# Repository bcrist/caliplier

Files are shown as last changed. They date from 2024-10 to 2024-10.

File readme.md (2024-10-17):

# Digital Caliper USB interface & LED Display

This project interfaces with the serial data output port found on cheap digital calipers.  It does several things:

* Provides power to the calipers
* Provides a second readout which isn't physically constrained by the measurement location/orientation
* Emulates a USB HID keyboard and "types" the current measurement at the press of a button
* Emulates a USB CDC-ACM serial port for logging/debug

There are many different variations on the serial format output by different calipers.  Some use 24-bit integers, some use BCD.  Some always output in inches, some always in mm, and some in whatever format the internal display is currently using.  Some include error detection data, others don't.  Currently there is only one protocol supported:

* Data signal is stable whenever Clock signal is high
* 24-bit packet, transferred over 8.1ms (+/- 0.1ms)
* First bit is always 1
* Next 20 bits are the unsigned magnitude (little-endian)
* Next bit is 1 if negative
* Last two bits are unused
* There is no indication whether it is in mm or inches mode.  In mm mode, 1 ULP is 0.01mm, and in inches mode, 1 ULP is 0.0005".
* The bus is idle for at least 5ms between packets



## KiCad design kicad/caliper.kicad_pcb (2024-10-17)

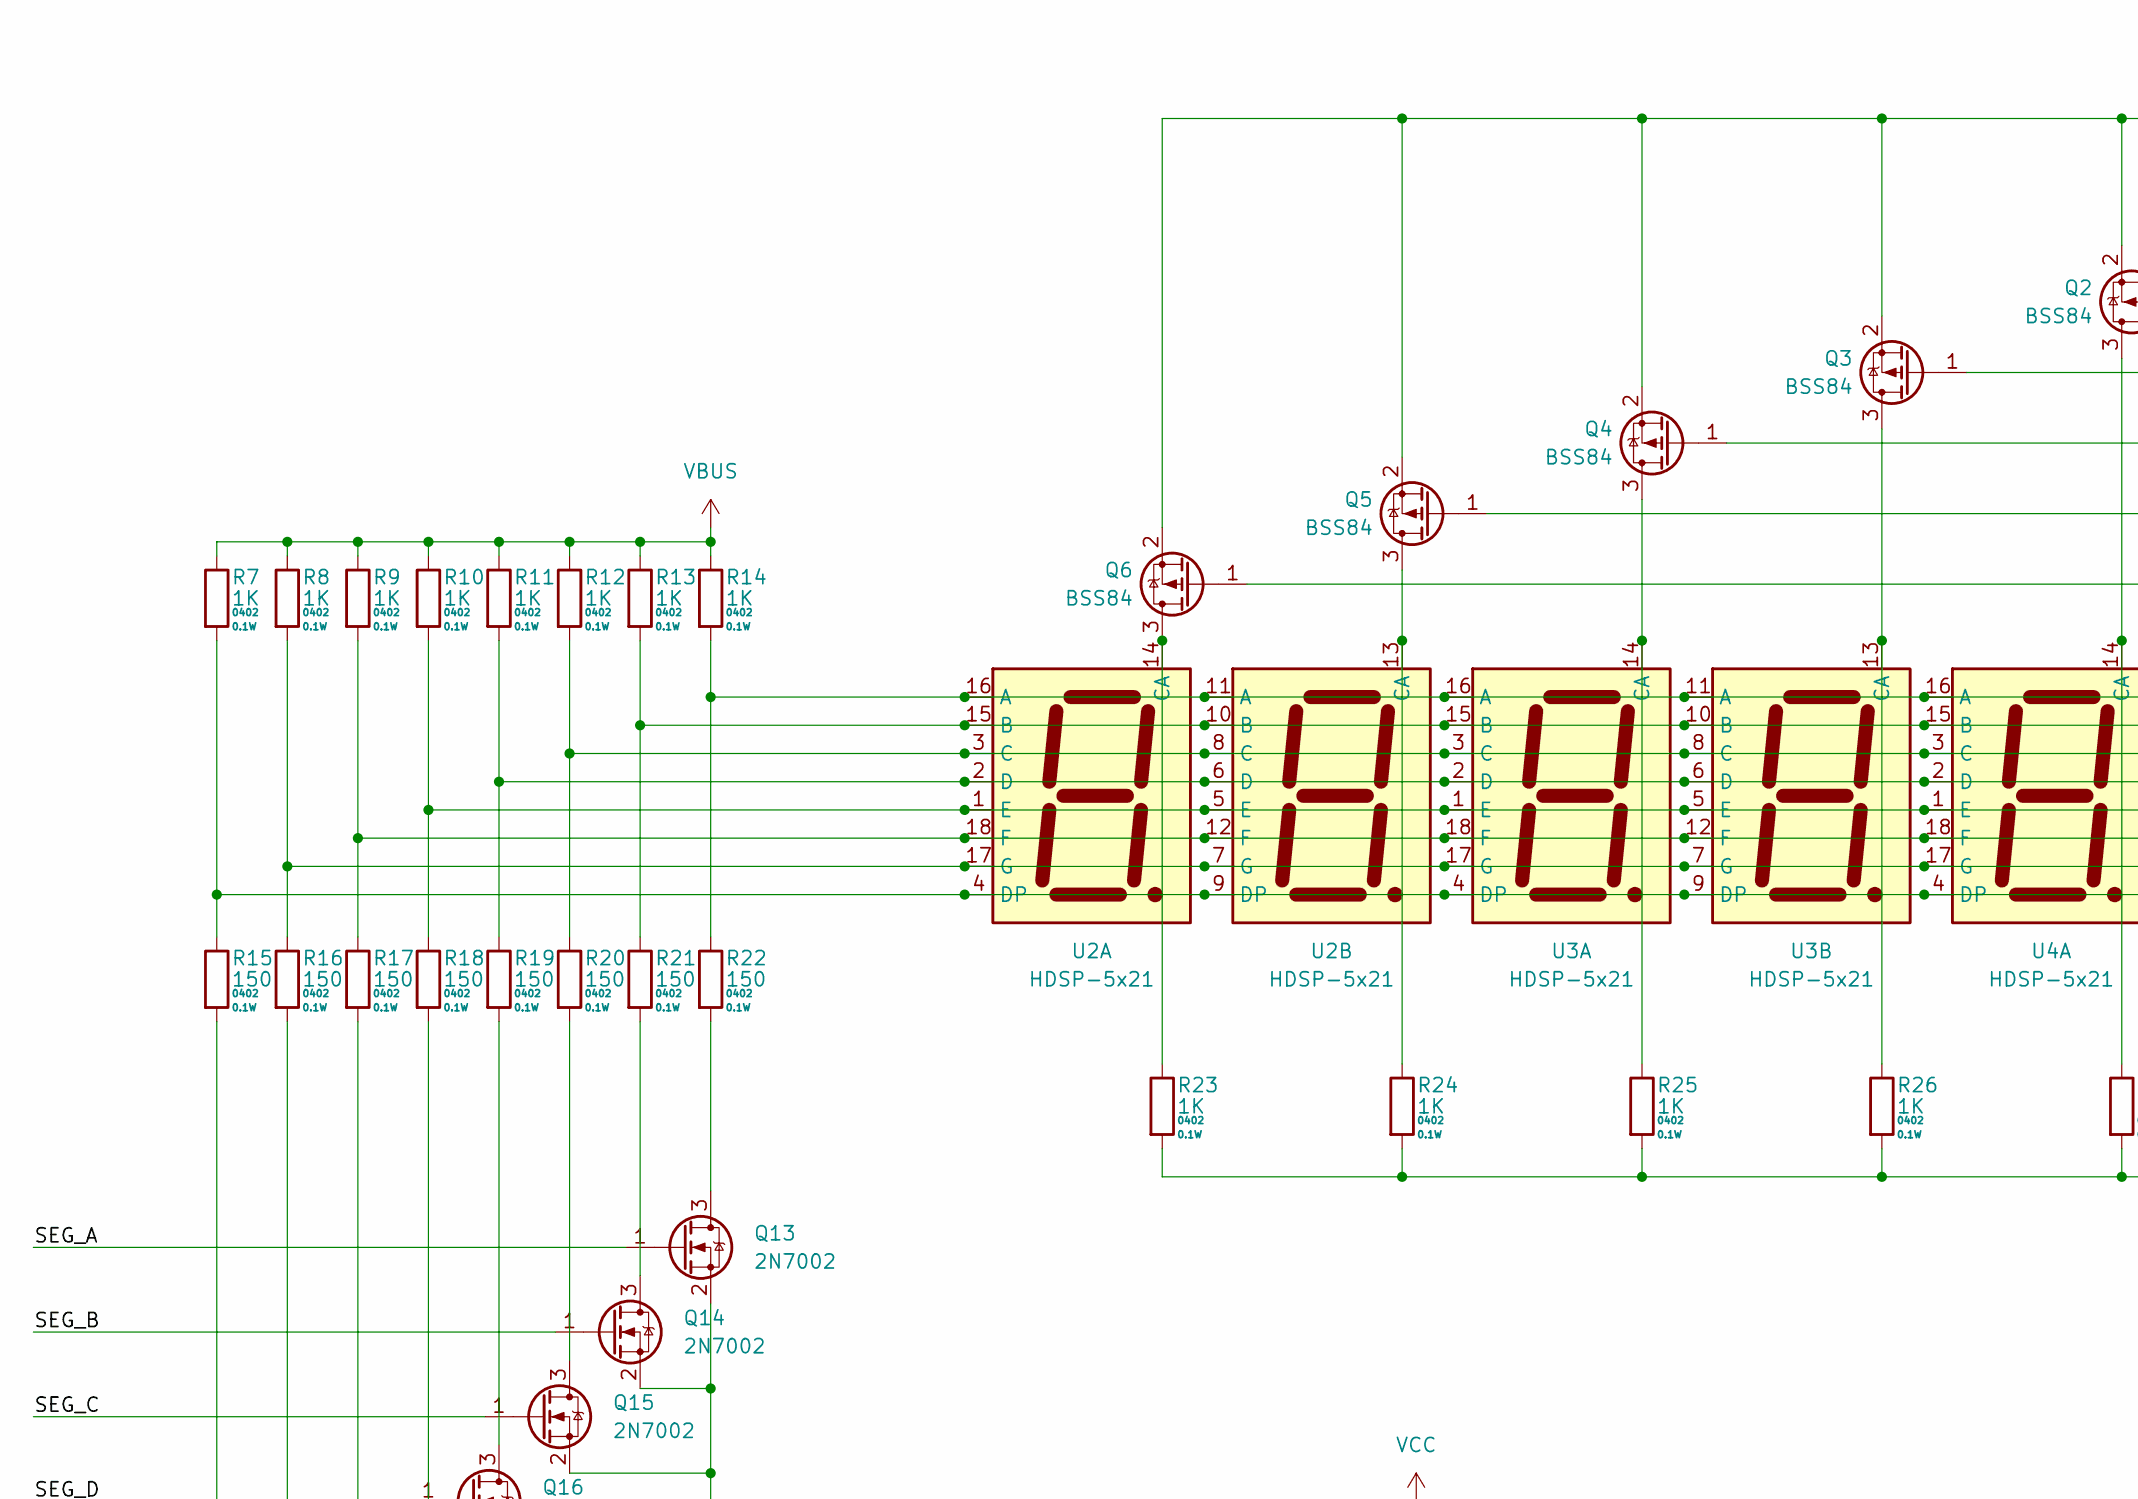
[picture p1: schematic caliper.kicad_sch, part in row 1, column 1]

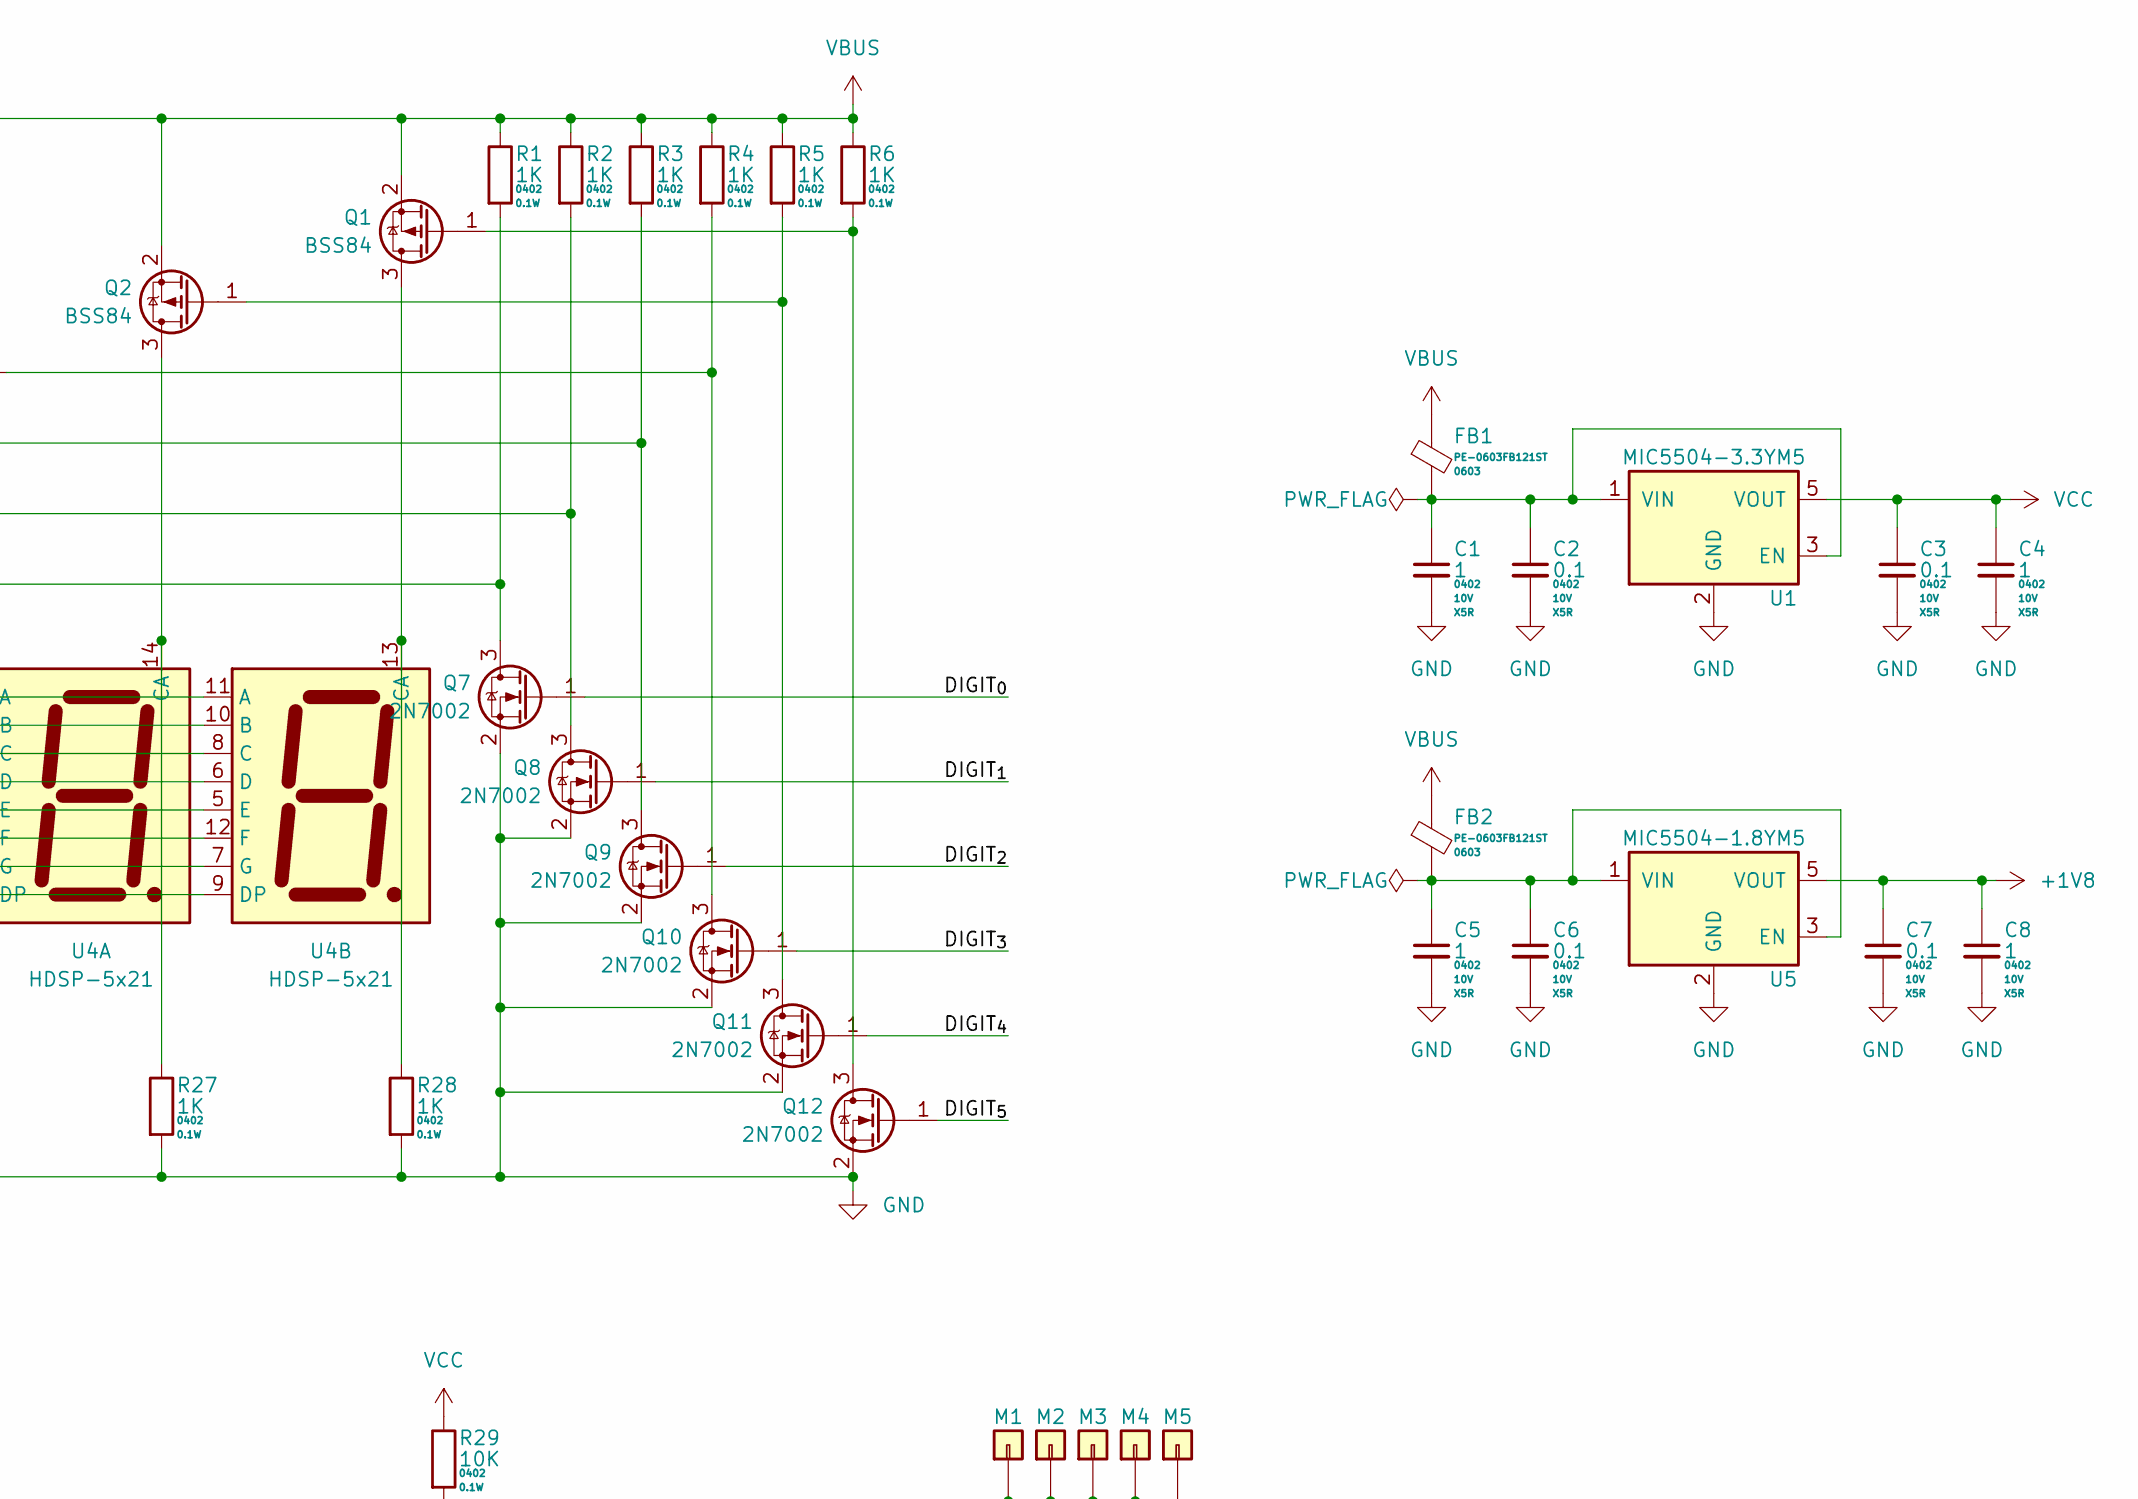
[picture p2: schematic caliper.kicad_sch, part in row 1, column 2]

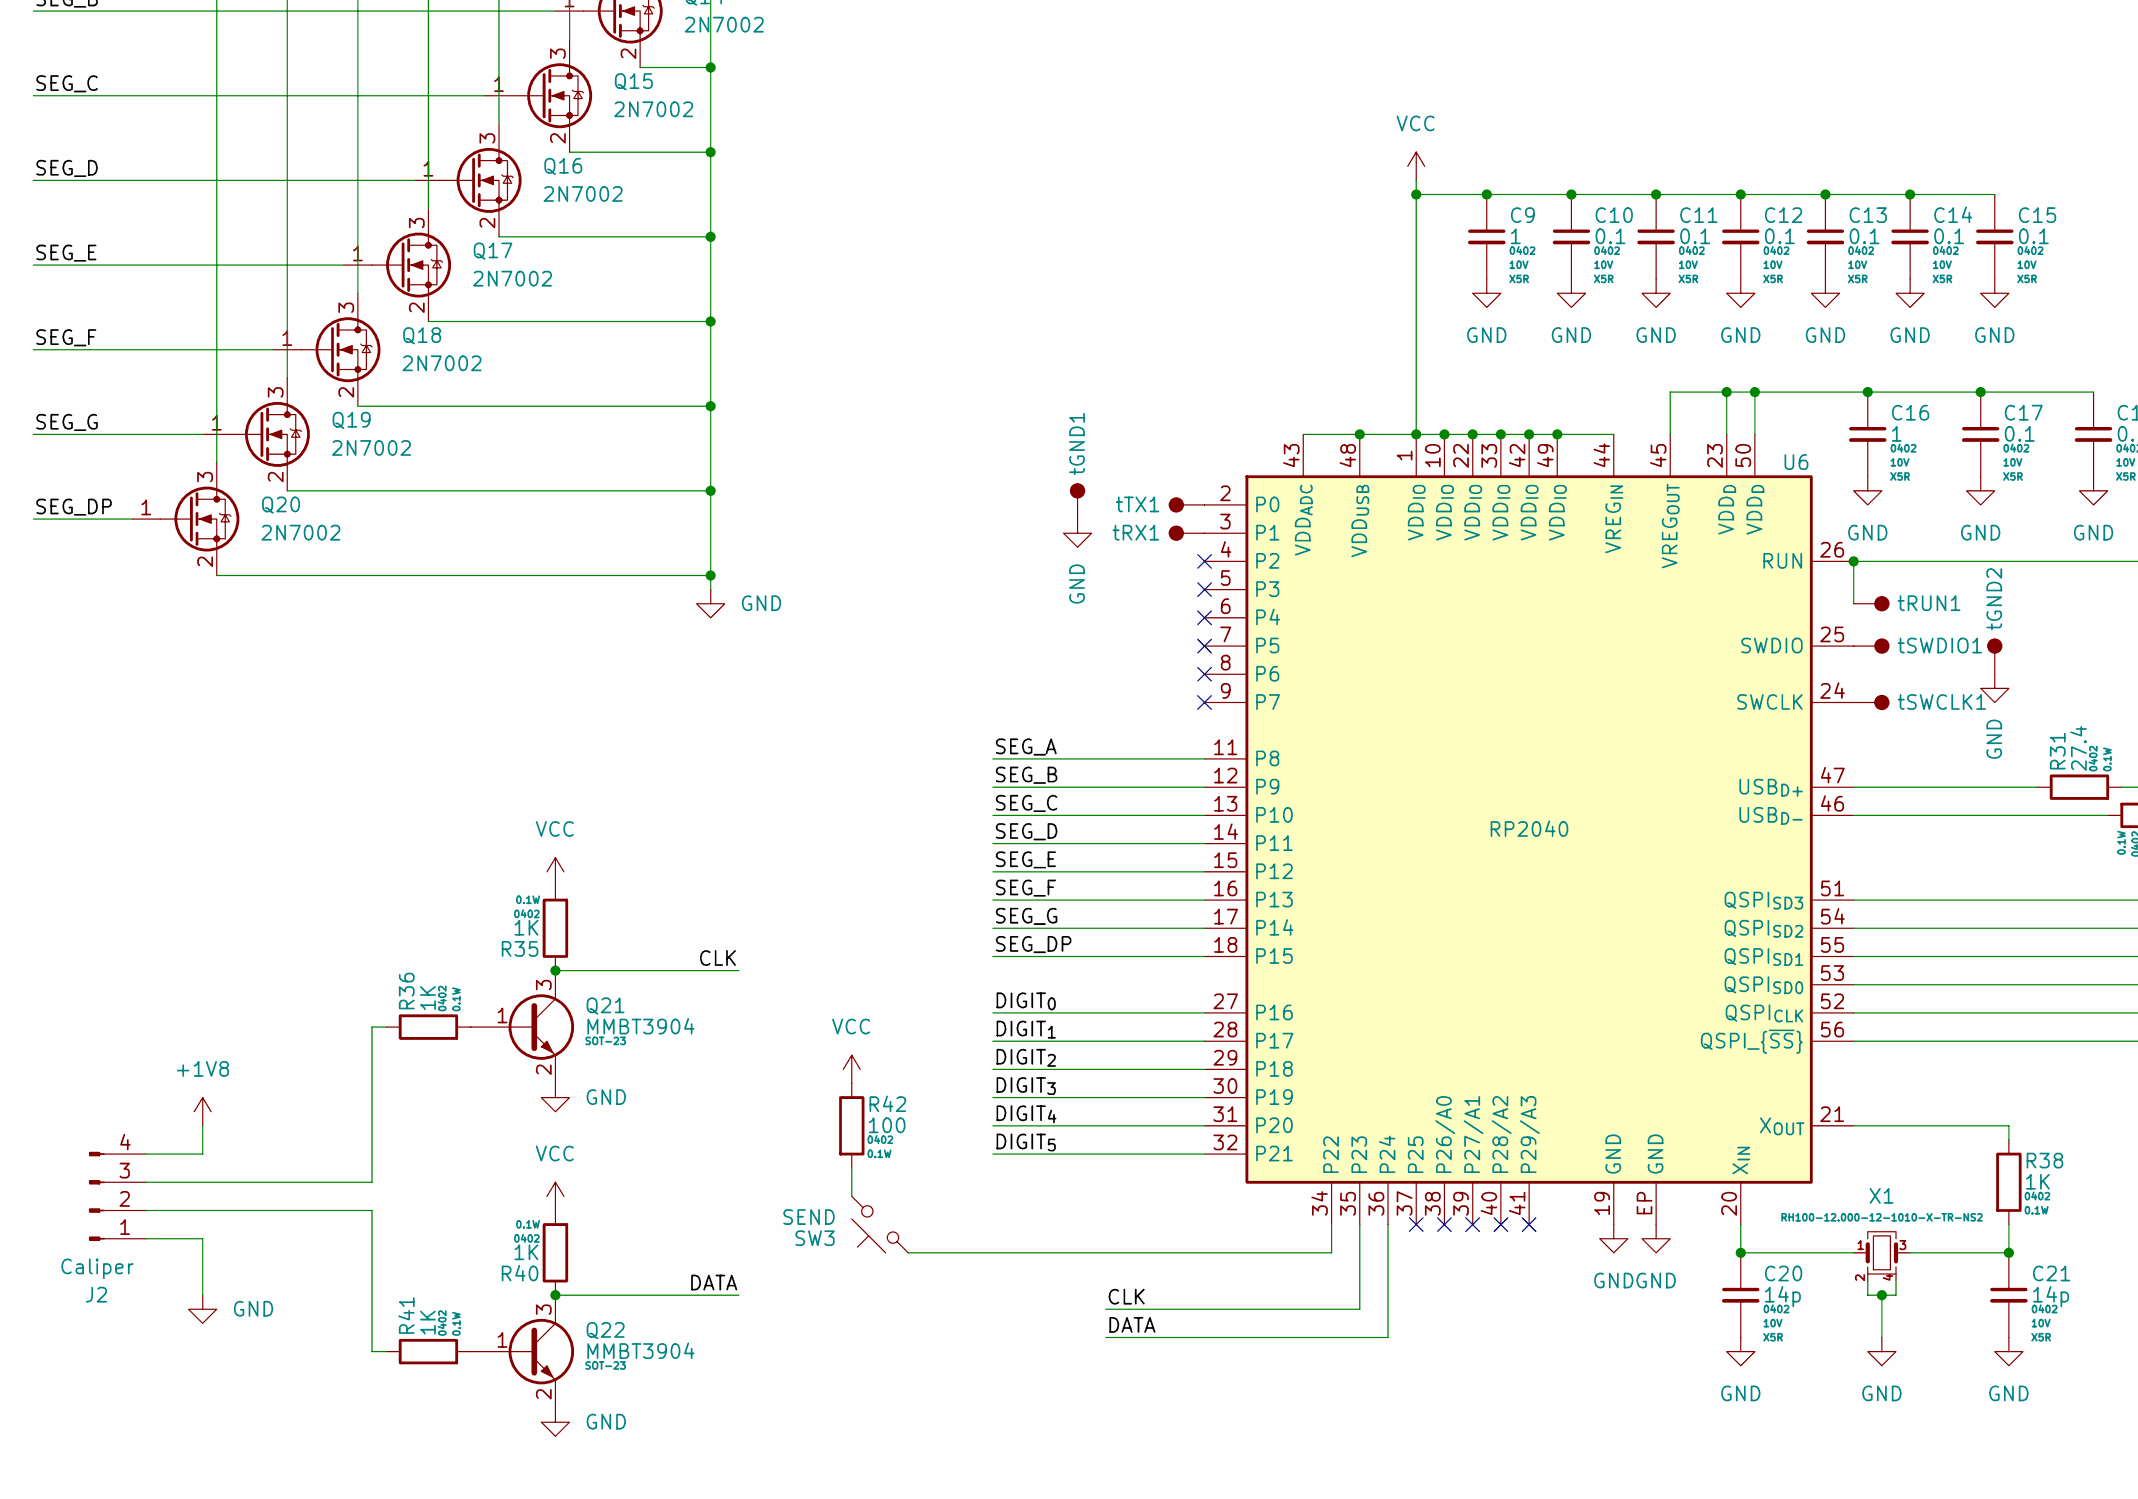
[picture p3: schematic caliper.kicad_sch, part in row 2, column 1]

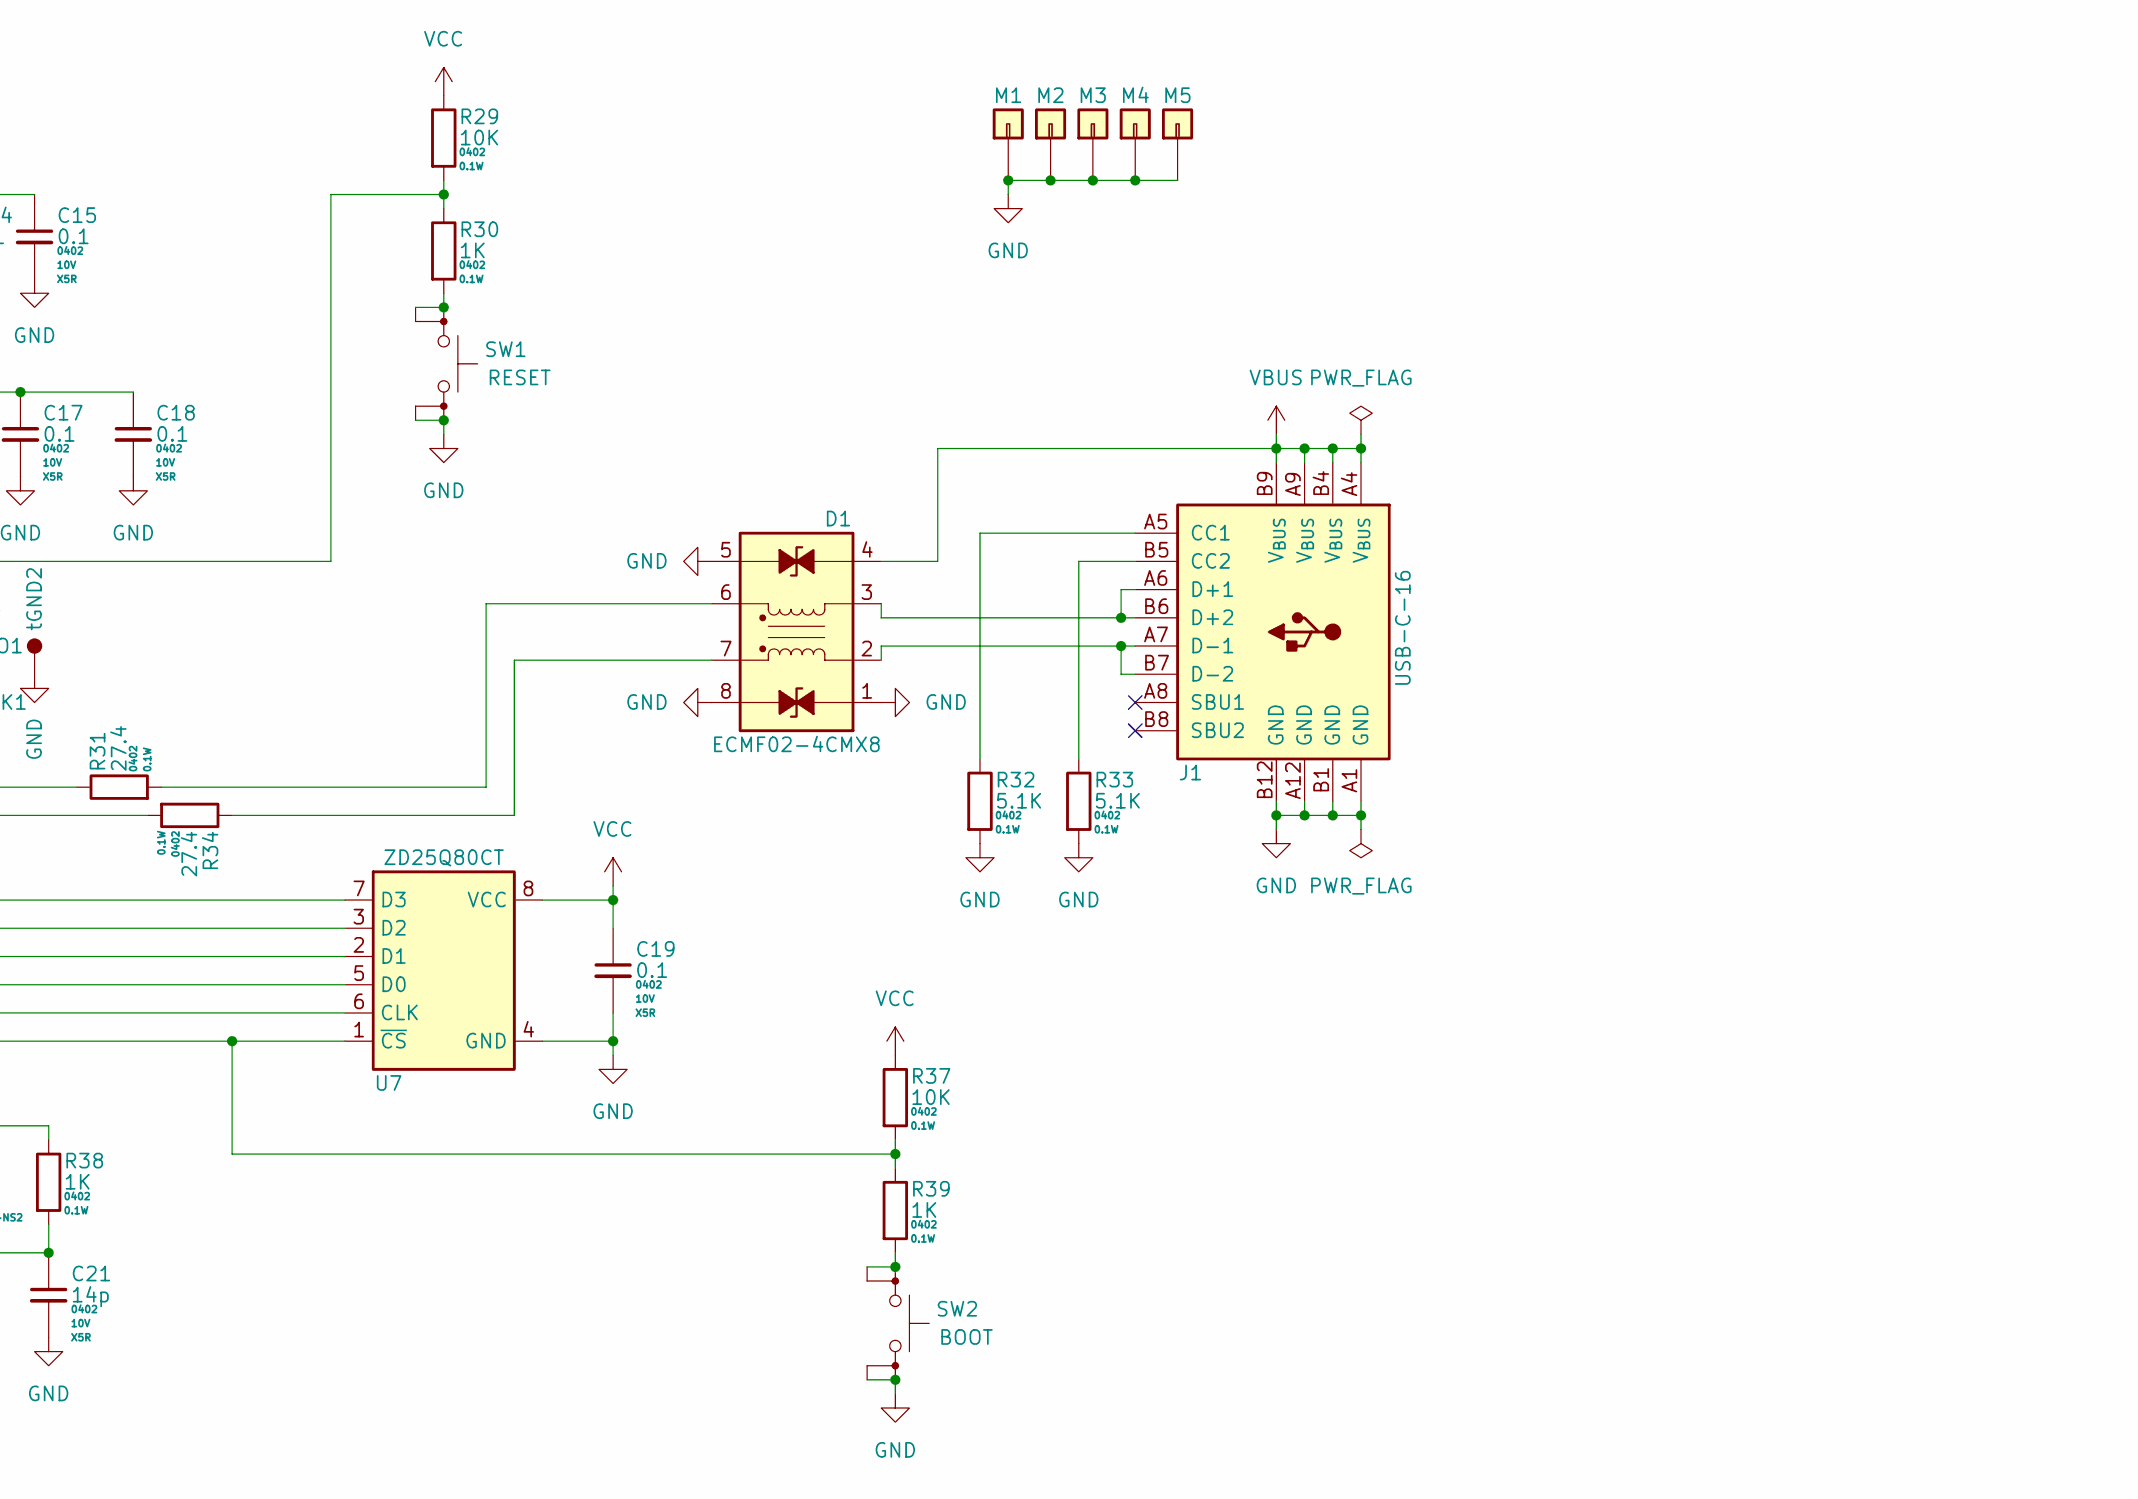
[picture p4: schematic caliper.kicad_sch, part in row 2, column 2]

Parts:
C1, C4, C5, C8, C9, C16: 1; C_0402; Voltage 10V
C2, C3, C6, C7, C10, C11, C12, C13, C14, C15, C17, C18, C19: 0.1; C_0402; Voltage 10V
C20, C21: 14p; C_0402; Voltage 10V
D1: ECMF02-4CMX8; DFN-8-2.5x1.2-P0.45
FB1, FB2: PE-0603FB121ST; L_0603
J1: USB-C-16; USB_GCT_USB4085-FG-A
J2: Caliper; PinHeader_1x04_P2.54mm_Vertical
M1, M2, M3, M4, M5: GND; MountingHole_3.2mm_M3_Pad_Via
Q1, Q2, Q3, Q4, Q5, Q6: BSS84; SOT-23
Q7, Q8, Q9, Q10, Q11, Q12, Q13, Q14, Q15, Q16, Q17, Q18, Q19, Q20: 2N7002; SOT-23
Q21, Q22: MMBT3904; SOT-23
R1, R2, R3, R4, R5, R6, R7, R8, R9, R10, R11, R12, R13, R14, R23, R24, R25, R26, R27, R28, R30, R35, R36, R38, R39, R40, R41: 1K; R_0402
R15, R16, R17, R18, R19, R20, R21, R22: 150; R_0402
R29, R37: 10K; R_0402
R31, R34: 27.4; R_0402
R32, R33: 5.1K; R_0402
R42: 100; R_0402
SW1: RESET; SW_CK_PTS526_SM15
SW2: BOOT; SW_CK_PTS526_SM15
SW3: SEND; SW_Cherry_MX1A_1.00u_Plate_Centered
U1: MIC5504-3.3YM5; SOT-23-5
U2, U3, U4: HDSP-5x21
U5: MIC5504-1.8YM5; SOT-23-5
U6: RP2040; QFN-56-EP-7x7-P0.4
U7: ZD25Q80CT; SOP-8-4.9x3.9-P1.27
X1: RH100-12.000-12-1010-X-TR-NS2
tGND1, tGND2: GND; TestPoint
tRUN1: VCC; TestPoint
tRX1: RX; TestPoint
tSWCLK1: SWCLK; TestPoint
tSWDIO1: SWDIO; TestPoint
tTX1: TX; TestPoint

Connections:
+1V8: C7.1, C8.1, J2.4, U5.5 (VOUT)
/CLK: Q21.3 (C), R35.1, U6.35 (P23)
/DATA: Q22.3 (C), R40.1, U6.36 (P24)
/DIGIT_{0}: Q7.1 (G), U6.27 (P16)
/DIGIT_{1}: Q8.1 (G), U6.28 (P17)
/DIGIT_{2}: Q9.1 (G), U6.29 (P18)
/DIGIT_{3}: Q10.1 (G), U6.30 (P19)
/DIGIT_{4}: Q11.1 (G), U6.31 (P20)
/DIGIT_{5}: Q12.1 (G), U6.32 (P21)
/SEG_A: Q13.1 (G), U6.11 (P8)
/SEG_B: Q14.1 (G), U6.12 (P9)
/SEG_C: Q15.1 (G), U6.13 (P10)
/SEG_D: Q16.1 (G), U6.14 (P11)
/SEG_DP: Q20.1 (G), U6.18 (P15)
/SEG_E: Q17.1 (G), U6.15 (P12)
/SEG_F: Q18.1 (G), U6.16 (P13)
/SEG_G: Q19.1 (G), U6.17 (P14)
GND: C1.2, C2.2, C3.2, C4.2, C5.2, C6.2, C7.2, C8.2, C9.2, C10.2, C11.2, C12.2, C13.2, C14.2, C15.2, C16.2, C17.2, C18.2, C19.2, C20.2, C21.2, D1.1, D1.5, D1.8, J1.A1 (GND), J1.A12 (GND), J1.B1 (GND), J1.B12 (GND), J2.1, M1.1, M2.1, M3.1, M4.1, M5.1, Q7.2 (S), Q8.2 (S), Q9.2 (S), Q10.2 (S), Q11.2 (S), Q12.2 (S), Q13.2 (S), Q14.2 (S), Q15.2 (S), Q16.2 (S), Q17.2 (S), Q18.2 (S), Q19.2 (S), Q20.2 (S), Q21.2 (E), Q22.2 (E), R23.2, R24.2, R25.2, R26.2, R27.2, R28.2, R32.2, R33.2, SW1.3, SW1.4, SW2.3, SW2.4, U1.2 (GND), U5.2 (GND), U6.19 (GND), U6.EP (GND), U7.4 (GND), X1.2, X1.4, tGND1.1, tGND2.1
unnamed: C21.1, R38.2, X1.3
unnamed: D1.6, R31.2
unnamed: D1.7, R34.1
unnamed: J1.A5 (CC1), R32.1
unnamed: J1.B5 (CC2), R33.1
unnamed: D1.3, J1.A6 (D+1), J1.B6 (D+2)
unnamed: D1.2, J1.A7 (D-1), J1.B7 (D-2)
unnamed: J2.2, R41.1
unnamed: J2.3, R36.1
unnamed: Q1.3 (D), R28.1, U4.13 (CA)
unnamed: Q1.1 (G), Q12.3 (D), R6.2
unnamed: Q2.3 (D), R27.1, U4.14 (CA)
unnamed: Q3.3 (D), R26.1, U3.13 (CA)
unnamed: Q4.3 (D), R25.1, U3.14 (CA)
unnamed: Q4.1 (G), Q9.3 (D), R3.2
unnamed: Q5.3 (D), R24.1, U2.13 (CA)
unnamed: Q5.1 (G), Q8.3 (D), R2.2
unnamed: Q6.3 (D), R23.1, U2.14 (CA)
unnamed: Q6.1 (G), Q7.3 (D), R1.2
unnamed: Q3.1 (G), Q10.3 (D), R4.2
unnamed: Q2.1 (G), Q11.3 (D), R5.2
unnamed: Q13.3 (D), R22.2
unnamed: Q14.3 (D), R21.2
unnamed: Q15.3 (D), R20.2
unnamed: Q16.3 (D), R19.2
unnamed: Q17.3 (D), R18.2
unnamed: Q18.3 (D), R17.2
unnamed: Q19.3 (D), R16.2
unnamed: Q20.3 (D), R15.2
unnamed: Q21.1 (B), R36.2
unnamed: Q22.1 (B), R41.2
unnamed: R30.2, SW1.1, SW1.2
unnamed: R39.2, SW2.1, SW2.2
unnamed: R42.2, SW3.2
unnamed: C1.1, C2.1, FB1.2, U1.1 (VIN), U1.3 (EN)
unnamed: R14.2, R22.1, U2.11 (A), U2.16 (A), U3.11 (A), U3.16 (A), U4.11 (A), U4.16 (A)
unnamed: R13.2, R21.1, U2.10 (B), U2.15 (B), U3.10 (B), U3.15 (B), U4.10 (B), U4.15 (B)
unnamed: R12.2, R20.1, U2.3 (C), U2.8 (C), U3.3 (C), U3.8 (C), U4.3 (C), U4.8 (C)
unnamed: R11.2, R19.1, U2.2 (D), U2.6 (D), U3.2 (D), U3.6 (D), U4.2 (D), U4.6 (D)
unnamed: R7.2, R15.1, U2.4 (DP), U2.9 (DP), U3.4 (DP), U3.9 (DP), U4.4 (DP), U4.9 (DP)
unnamed: R10.2, R18.1, U2.1 (E), U2.5 (E), U3.1 (E), U3.5 (E), U4.1 (E), U4.5 (E)
unnamed: R9.2, R17.1, U2.12 (F), U2.18 (F), U3.12 (F), U3.18 (F), U4.12 (F), U4.18 (F)
unnamed: R8.2, R16.1, U2.7 (G), U2.17 (G), U3.7 (G), U3.17 (G), U4.7 (G), U4.17 (G)
unnamed: C5.1, C6.1, FB2.2, U5.1 (VIN), U5.3 (EN)
unnamed: U6.2 (P0), tTX1.1
unnamed: U6.3 (P1), tRX1.1
unnamed: SW3.1, U6.34 (P22)
unnamed: U6.52 (QSPI_{CLK}), U7.6 (CLK)
unnamed: U6.53 (QSPI_{SD0}), U7.5 (D0)
unnamed: U6.55 (QSPI_{SD1}), U7.2 (D1)
unnamed: U6.54 (QSPI_{SD2}), U7.3 (D2)
unnamed: U6.51 (QSPI_{SD3}), U7.7 (D3)
unnamed: R37.2, R39.1, U6.56 (QSPI_{~SS}), U7.1 (~CS)
unnamed: R29.2, R30.1, U6.26 (RUN), tRUN1.1
unnamed: U6.24 (SWCLK), tSWCLK1.1
unnamed: U6.25 (SWDIO), tSWDIO1.1
unnamed: R31.1, U6.47 (USB_{D+})
unnamed: R34.2, U6.46 (USB_{D-})
unnamed: C16.1, C17.1, C18.1, U6.23 (VDD_{D}), U6.45 (VREG_{OUT}), U6.50 (VDD_{D})
unnamed: C20.1, U6.20 (X_{IN}), X1.1
unnamed: R38.1, U6.21 (X_{OUT})
VBUS: D1.4, FB1.1, FB2.1, J1.A4 (V_{BUS}), J1.A9 (V_{BUS}), J1.B4 (V_{BUS}), J1.B9 (V_{BUS}), Q1.2 (S), Q2.2 (S), Q3.2 (S), Q4.2 (S), Q5.2 (S), Q6.2 (S), R1.1, R2.1, R3.1, R4.1, R5.1, R6.1, R7.1, R8.1, R9.1, R10.1, R11.1, R12.1, R13.1, R14.1
VCC: C3.1, C4.1, C9.1, C10.1, C11.1, C12.1, C13.1, C14.1, C15.1, C19.1, R29.1, R35.2, R37.1, R40.2, R42.1, U1.5 (VOUT), U6.1 (VDD_{IO}), U6.10 (VDD_{IO}), U6.22 (VDD_{IO}), U6.33 (VDD_{IO}), U6.42 (VDD_{IO}), U6.43 (VDD_{ADC}), U6.44 (VREG_{IN}), U6.48 (VDD_{USB}), U6.49 (VDD_{IO}), U7.8 (VCC)

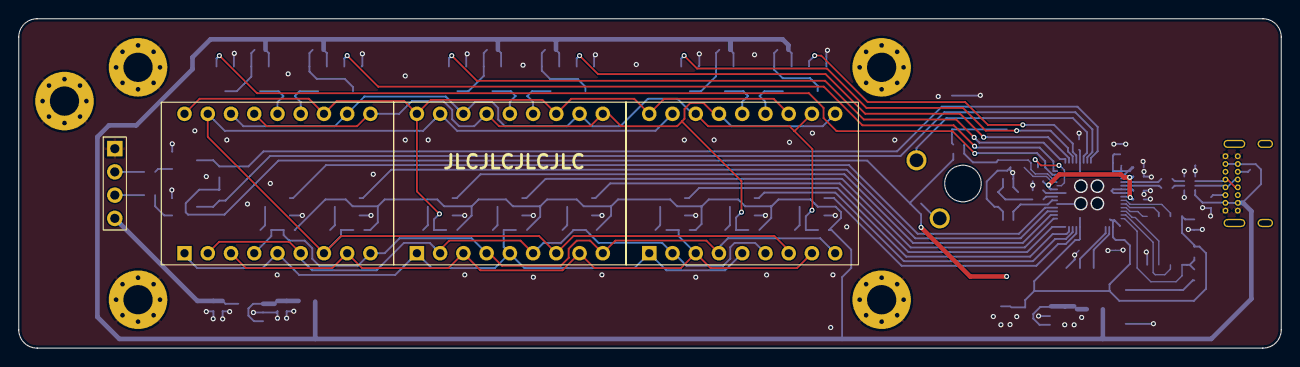
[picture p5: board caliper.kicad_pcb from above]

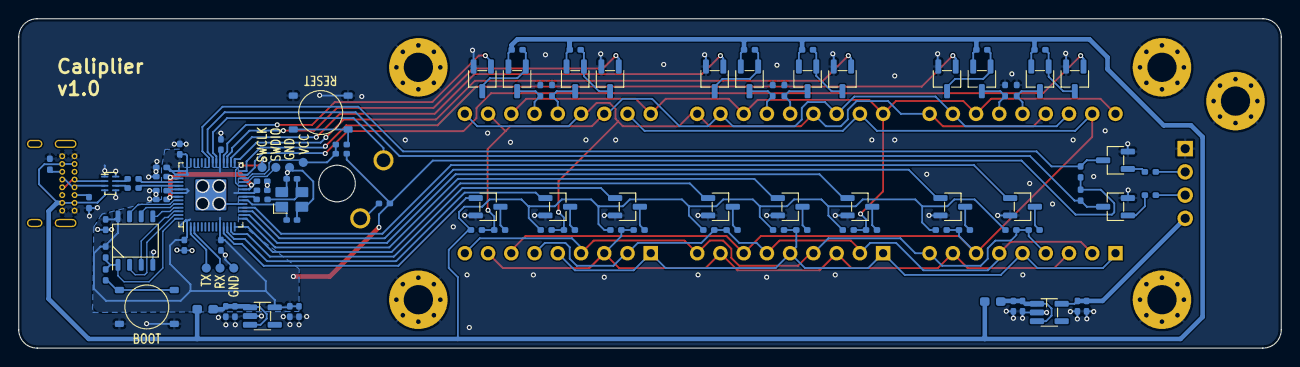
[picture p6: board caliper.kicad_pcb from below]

Board: 2 copper layers, 138.0 x 36.0 mm, 113 parts (102 on the bottom side), 81 nets.
